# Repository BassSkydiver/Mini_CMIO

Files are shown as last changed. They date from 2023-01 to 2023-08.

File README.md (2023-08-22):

# CMIOBoard
A tiny, compact IO board for the raspberry compute modules 1/3/3+

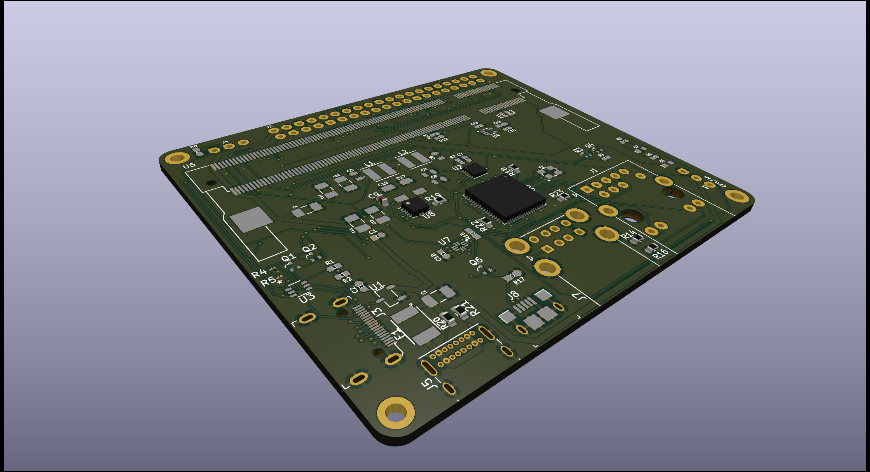
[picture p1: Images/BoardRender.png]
Top View


## Features:
IO Ports:  
* USB-C (Power/USB 2.0)
* HDMI
* USB-Micro B (Slave port)
* Dual-USB-A 2.0
* Ethernet

## Other:
* Three pin 5V fan header
* Three pin boot selector
* 40 pin standard Raspberry Pi GPIO
* 4x2.2mm mounting holes
* Power LED (Red)
* Boot LED (Green)

## Dimensions:
75.66mm x 65.63mm  
2.844mm radius rounded corners
2.2mm diameter mounting holes (M2 or US #1/2 screws)  
69.97mm center distance between horizontally aligned mounting holes.  
59.94mm center distance between vertically aligned mounting holes.  
## Important!
The Raspberry Pi Compute Module requires a 5v, 2+ Amp power supply. (5.1V Recommended)
This board was made by a complete amatuer and should be avoided or subject to harsh scrutiny before used in a real application.

## Directions to Install:
1. Make sure your KiCAD verison is 7.0.6 or higher
2. Rename the "Footprints" folder to "Footprints.pretty"
3. Open the "RPCM1 IO Board.kicad_pro" file
4. Add symbols and footprints from this directory into the "Project Specific Libraries" section of the Symbol Library Manager and the Footprint Library Manager
5. Do whatever you want I guess :)

*License: GNU General Public License v3.0*  
*[gnu.org/licenses/gpl-3.0](https://www.gnu.org/licenses/gpl-3.0.en.html)*

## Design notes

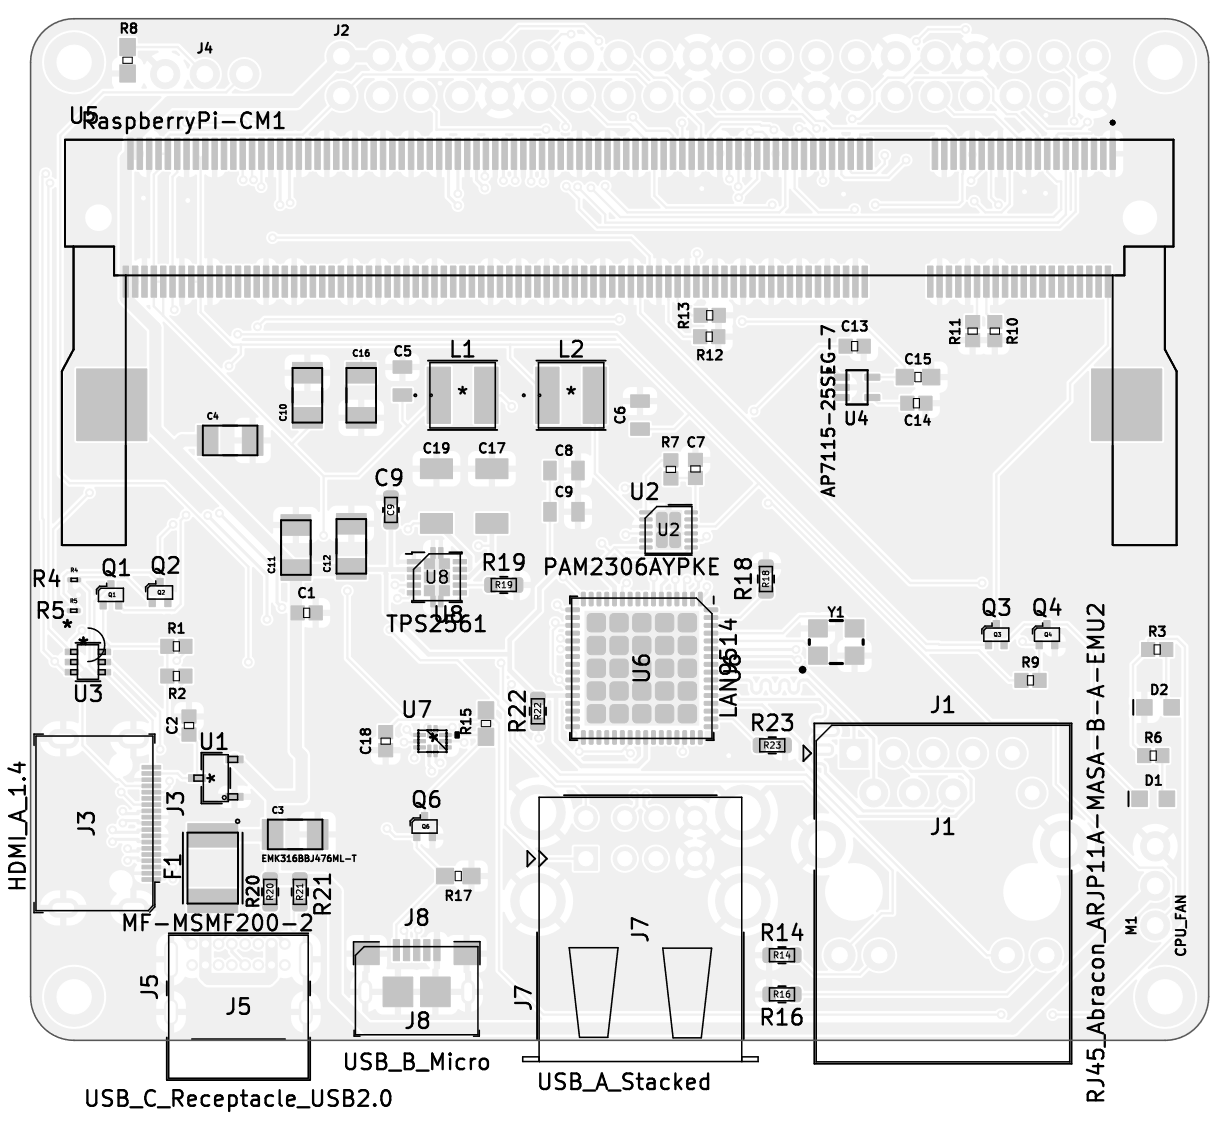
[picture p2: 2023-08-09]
Images/BoardTop.png

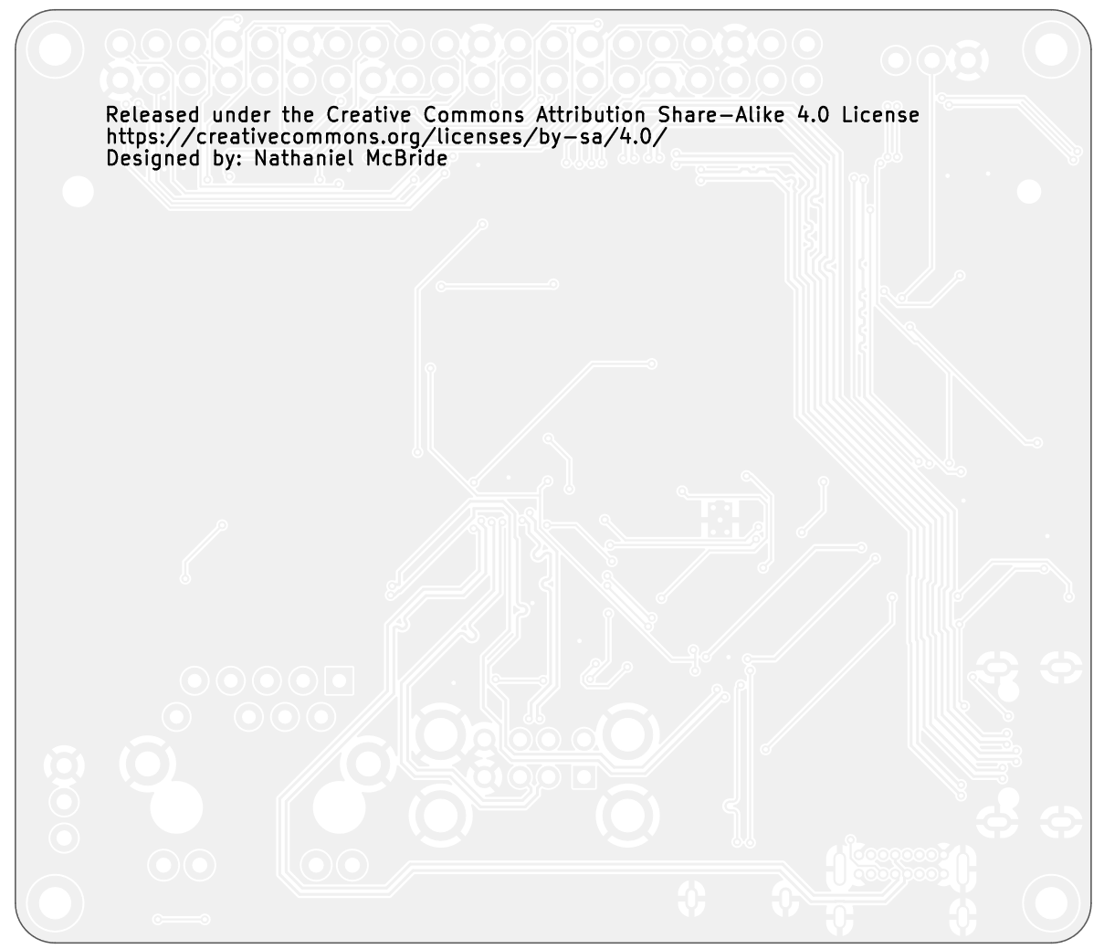
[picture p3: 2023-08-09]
Images/BoardBot.png

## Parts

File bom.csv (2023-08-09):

Reference | Value | Footprint | Datasheet | ARROW_ELECTRONICS-PURCHASE-URL | AVAILABILITY | Category | DESCRIPTION | DIGIKEY-PURCHASE-URL | DK_Datasheet_Link | DK_Detail_Page | Description | Digi-Key_PN | Family | Field4 | Height | MANUFACTURER | MF | MOUSER-PURCHASE-URL | MP | MPN | Manufacturer | Manufacturer_Name | Manufacturer_Part_Number | Mouser Part Number | Mouser Price/Stock | PACKAGE | PARTREV | PRICE | STANDARD | Status | Qty
C1, C2, C7, C14 | 0.1UF-0402 | Capacitors:0402 |  |  |  |  |  |  |  |  |  |  |  | CAP-12416 |  |  |  |  |  |  |  |  |  |  |  |  |  |  |  |  | 4
C3, C4, C10-C12, C16 | EMK316BBJ476ML-T | custom:CAPC3216X190N |  |  |  |  |  |  |  |  |  |  |  |  |  |  |  |  |  |  |  |  |  |  |  |  |  |  |  |  | 6
C5, C6 | 10UF-0805 | Capacitors:0805 |  |  |  |  |  |  |  |  |  |  |  | CAP-11330 |  |  |  |  |  |  |  |  |  |  |  |  |  |  |  |  | 2
C8 | 10UF-0805-10V-10% | Capacitors:0805 |  |  |  |  |  |  |  |  |  |  |  | CAP-11330 |  |  |  |  |  |  |  |  |  |  |  |  |  |  |  |  | 1
C8/9 | 10UF-0805 | Capacitors:0805 |  |  |  |  |  |  |  |  |  |  |  | CAP-11330 |  |  |  |  |  |  |  |  |  |  |  |  |  |  |  |  | 1
C9 | 0.1UF-0603-25V-5% | Capacitor_SMD:C_0603_1608Metric |  |  |  |  |  |  |  |  |  |  |  | CAP-08604 |  |  |  |  |  |  |  |  |  |  |  |  |  |  |  |  | 1
C13 | 1.0UF-0402 | Capacitors:0402 |  |  |  |  |  |  |  |  |  |  |  | CAP-12417 |  |  |  |  |  |  |  |  |  |  |  |  |  |  |  |  | 1
C15 | 4.7UF-1206 | Capacitors:0603 |  |  |  |  |  |  |  |  |  |  |  |  |  |  |  |  |  |  |  |  |  |  |  |  |  |  |  |  | 1
C17, C19 | AMK325ABJ157MM-P | Capacitors:1210 | https://media.digikey.com/pdf/Data%20Sheets/Taiyo%20Yuden%20PDFs%20URL%20links/AMK325ABJ157MM-P_SS.pdf |  |  |  |  |  |  |  |  |  |  |  | 2.8 |  |  |  |  |  |  | TAIYO YUDEN | AMK325ABJ157MM-P | 963-AMK325ABJ157MM-P | https://www.mouser.co.uk/ProductDetail/Taiyo-Yuden/AMK325ABJ157MM-P?qs=GTwwGWkfii23ISUqIFLJMQ%3D%3D |  |  |  |  |  | 2
C18 | 0.1UF-0402-16V-10% | Capacitors:0402 |  |  |  |  |  |  |  |  |  |  |  | CAP-12416 |  |  |  |  |  |  |  |  |  |  |  |  |  |  |  |  | 1
D1 | LED-GREEN0603 | LED:LED-0603 |  |  |  |  |  |  |  |  |  |  |  | DIO-00821 |  |  |  |  |  |  |  |  |  |  |  |  |  |  |  |  | 1
D2 | LED-RED0603 | LED:LED-0603 |  |  |  |  |  |  |  |  |  |  |  | DIO-00819 |  |  |  |  |  |  |  |  |  |  |  |  |  |  |  |  | 1
F1 | MF-MSMF200-2 | custom:MF-MSMF200-2 |  | https://snapeda.com/shop?store=Arrow+Electronics&id=143366 | Good |  | Polymeric PTC Resettable Fuse 8V 2A Ih Surface Mount 1812 (4532 Metric), Concave | https://snapeda.com/shop?store=DigiKey&id=143366 |  |  |  |  |  |  |  |  | Bourns | https://snapeda.com/shop?store=Mouser&id=143366 | MF-MSMF200-2 |  |  |  |  |  |  | 1812 Bourns |  | None |  |  | 1
H1-H4 | MountingHole | MountingHole:MountingHole_2.2mm_M2_DIN965_Pad_TopBottom | ~ |  |  |  |  |  |  |  |  |  |  |  |  |  |  |  |  |  |  |  |  |  |  |  |  |  |  |  | 4
J1 | RJ45_Abracon_ARJP11A-MASA-B-A-EMU2 | Connector_RJ:RJ45_Abracon_ARJP11A-MA_Horizontal | https://abracon.com/Magnetics/lan/ARJP11A.PDF |  |  |  |  |  |  |  |  |  |  |  |  |  |  |  |  |  |  |  |  |  |  |  |  |  |  |  | 1
J2 | RASPBERRYPI-40-PIN-GPIO_PTH | Connectors:2X20_NOSILK |  |  |  |  |  |  |  |  |  |  |  | CONN-12263 |  |  |  |  |  |  |  |  |  |  |  |  |  |  |  |  | 1
J3 | HDMI_A_1.4 | digikey-footprints:HDMI_Mini_Female_2001-1-2-21-00-BK | https://en.wikipedia.org/wiki/HDMI |  |  |  |  |  |  |  |  |  |  |  |  |  |  |  |  |  |  |  |  |  |  |  |  |  |  |  | 1
J4 | CONN_03 | Connectors:1X03_NO_SILK |  |  |  |  |  |  |  |  |  |  |  | XXX-00000 |  |  |  |  |  |  |  |  |  |  |  |  |  |  |  |  | 1
J5 | USB_C_Receptacle_USB2.0 | Connector_USB:USB_C_Receptacle_GCT_USB4085 | https://www.usb.org/sites/default/files/documents/usb_type-c.zip |  |  |  |  |  |  |  |  |  |  |  |  |  |  |  |  |  |  |  |  |  |  |  |  |  |  |  | 1
J7 | USB_A_Stacked | Connector_USB:USB_A_CUI_UJ2-ADH-TH_Horizontal_Stacked | ~ |  |  |  |  |  |  |  |  |  |  |  |  |  |  |  |  |  |  |  |  |  |  |  |  |  |  |  | 1
J8 | USB_B_Micro | digikey-footprints:USB_Micro_B_Female_10118193-0001LF | ~ |  |  |  |  |  |  |  |  |  |  |  |  |  |  |  |  |  |  |  |  |  |  |  |  |  |  |  | 1
L1, L2 | SRN4018-4R7M | custom:SRN4018-4R7M |  |  |  |  |  |  |  |  |  |  |  |  |  |  |  |  |  |  |  |  |  |  |  |  |  |  |  |  | 2
M1 | Fan_3pin | Connectors:1X03_NO_SILK | http://www.hardwarecanucks.com/forum/attachments/new-builds/16287d1330775095-help-chassis-power-fan-connectors-motherboard-asus_p8z68.jpg |  |  |  |  |  |  |  |  |  |  |  |  |  |  |  |  |  |  |  |  |  |  |  |  |  |  |  | 1
Q1-Q4, Q6 | DMG1012T-7 | digikey-footprints:SOT-523 | https://www.diodes.com/assets/Datasheets/ds31783.pdf |  |  | Discrete Semiconductor Products |  |  | https://www.diodes.com/assets/Datasheets/ds31783.pdf | /product-detail/en/diodes-incorporated/DMG1012T-7/DMG1012T-7DICT-ND/2181232 | MOSFET N-CH 20V 630MA SOT-523 | DMG1012T-7DICT-ND | Transistors - FETs, MOSFETs - Single |  |  |  |  |  |  | DMG1012T-7 | Diodes Incorporated |  |  |  |  |  |  |  |  | Active | 5
R1, R2 | RESISTOR0402 | Resistors:0402 |  |  |  |  |  |  |  |  |  |  |  |  |  |  |  |  |  |  |  |  |  |  |  |  |  |  |  |  | 2
R3 | 470OHM | Resistors:0402 |  |  |  |  |  |  |  |  |  |  |  | RES-07869 |  |  |  |  |  |  |  |  |  |  |  |  |  |  |  |  | 1
R4, R5 | 100K-0402 | Resistor_SMD:R_01005_0402Metric |  |  |  |  |  |  |  |  |  |  |  | RES-13495 |  |  |  |  |  |  |  |  |  |  |  |  |  |  |  |  | 2
R6 | 470-0402 | Resistors:0402 |  |  |  |  |  |  |  |  |  |  |  | RES-07869 |  |  |  |  |  |  |  |  |  |  |  |  |  |  |  |  | 1
R7 | 100k-0402 | Resistors:0402 |  |  |  |  |  |  |  |  |  |  |  | RES-13495 |  |  |  |  |  |  |  |  |  |  |  |  |  |  |  |  | 1
R8 | 47K-0603 | Resistors:0603 |  |  |  |  |  |  |  |  |  |  |  | RES-07871 |  |  |  |  |  |  |  |  |  |  |  |  |  |  |  |  | 1
R9 | 100K-0402 | Resistors:0402 |  |  |  |  |  |  |  |  |  |  |  | RES-13495 |  |  |  |  |  |  |  |  |  |  |  |  |  |  |  |  | 1
R10-R13 | 100KOHM-0402-1_16W-1% | Resistors:0402 |  |  |  |  |  |  |  |  |  |  |  | RES-13495 |  |  |  |  |  |  |  |  |  |  |  |  |  |  |  |  | 4
R14, R16 | 100OHM-0603 | Resistor_SMD:R_0603_1608Metric |  |  |  |  |  |  |  |  |  |  |  | RES-12438 |  |  |  |  |  |  |  |  |  |  |  |  |  |  |  |  | 2
R15 | 47KOHM-0603-1_10W | Resistors:0603 |  |  |  |  |  |  |  |  |  |  |  | RES-07871 |  |  |  |  |  |  |  |  |  |  |  |  |  |  |  |  | 1
R17 | 47KOHM-0603-1_10W-1% | Resistors:0603 |  |  |  |  |  |  |  |  |  |  |  | RES-07871 |  |  |  |  |  |  |  |  |  |  |  |  |  |  |  |  | 1
R18 | 12KOHM-0603-1% | Resistor_SMD:R_0603_1608Metric |  |  |  |  |  |  |  |  |  |  |  | RES-10327 |  |  |  |  |  |  |  |  |  |  |  |  |  |  |  |  | 1
R19 | 100KOHM-0603-1_10W-1% | Resistor_SMD:R_0603_1608Metric |  |  |  |  |  |  |  |  |  |  |  | RES-07828 |  |  |  |  |  |  |  |  |  |  |  |  |  |  |  |  | 1
R20, R21 | 47KOHM-0603-1_10W-1% | Resistor_SMD:R_0603_1608Metric |  |  |  |  |  |  |  |  |  |  |  | RES-07871 |  |  |  |  |  |  |  |  |  |  |  |  |  |  |  |  | 2
R22 | 10KOHM-0603-1_10W-1% | Resistor_SMD:R_0603_1608Metric |  |  |  |  |  |  |  |  |  |  |  | RES-00824 |  |  |  |  |  |  |  |  |  |  |  |  |  |  |  |  | 1
R23 | 12KOHM-0603 | Resistor_SMD:R_0603_1608Metric |  |  |  |  |  |  |  |  |  |  |  | RES-10327 |  |  |  |  |  |  |  |  |  |  |  |  |  |  |  |  | 1
U1 | AP2331W-7 | custom:AP2331W-7 |  |  |  |  |  |  |  |  |  |  |  |  |  |  |  |  |  |  |  |  |  |  |  |  |  |  |  |  | 1
U2 | PAM2306AYPKE | Package_DFN_QFN:WDFN-12-1EP_3x3mm_P0.45mm_EP1.7x2.5mm | https://www.diodes.com/assets/Datasheets/PAM2306.pdf |  |  |  |  |  |  |  |  |  |  |  |  |  |  |  |  |  |  |  |  |  |  |  |  |  |  |  | 1
U3 | PESD3V3L5UY | custom:PESD3V3L5UY |  |  |  |  |  |  |  |  |  |  |  |  |  |  |  |  |  |  |  |  |  |  |  |  |  |  |  |  | 1
U4 | AP7115-25SEG-7 | custom:AP7115-25SEG |  |  |  |  |  |  |  |  |  |  |  |  |  | Diodes Inc. |  |  |  |  |  |  |  |  |  |  | 12 | None | IPC7351B |  | 1
U5 | RaspberryPi-CM1 | custom:TE_1717254-4 | https://www.raspberrypi.org/documentation/hardware/computemodule/datasheets/rpi_DATA_CM_1p0.pdf |  |  |  |  |  |  |  |  |  |  |  |  |  |  |  |  |  |  |  |  |  |  |  |  |  |  |  | 1
U6 | LAN9514 | Package_DFN_QFN:QFN-64-1EP_9x9mm_P0.5mm_EP7.3x7.3mm | http://ww1.microchip.com/downloads/en/DeviceDoc/00002306A.pdf |  |  |  |  |  |  |  |  |  |  |  |  |  |  |  |  |  |  |  |  |  |  |  |  |  |  |  | 1
U7 | FSUSB42UMX | custom:FSUSB42UMX |  |  |  |  |  |  |  |  |  |  |  |  |  |  |  |  |  |  |  |  |  |  |  |  |  |  |  |  | 1
U8 | TPS2561 | Package_SON:VSON-10-1EP_3x3mm_P0.5mm_EP1.65x2.4mm_ThermalVias | http://www.ti.com/lit/ds/symlink/tps2561.pdf |  |  |  |  |  |  |  |  |  |  |  |  |  |  |  |  |  |  |  |  |  |  |  |  |  |  |  | 1
Y1 | ECS-250-10-37B-CTN-TR | Clocks:CRYSTAL-SMD-3.2X2.5MM |  |  |  |  |  |  |  |  |  |  |  |  |  | ECS INC |  |  |  |  |  |  |  |  |  | SMD-4 ECX | 2017 |  | Manufacturer Recommendation |  | 1

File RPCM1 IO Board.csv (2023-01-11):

Source: | C:\Users\natha\OneDrive\Documents\PCB Designs\RPCM1 IO Board\RPCM1 IO Board.kicad_sch
Date: | 1/9/2023 3:18:24 PM
Tool: | Eeschema (6.0.9)
Generator: | C:\Program Files\KiCad\6.0\bin\scripting\plugins/bom_csv_grouped_by_value_with_fp.py
Component Count: | 60
Ref | Qnty | Cmp name | DK Name | Description | Datasheet | Manufacturer | DK Link | Price (Single) | Price (Total)
C1, C2, C6, C12, C14, | 5 | 0.1UF-0402-16V-10% | 04026D104KAT2A | 0.1 µF ±10% 6.3V Ceramic Capacitor X5R 0402 (1005 Metric) | https://datasheets.kyocera-avx.com/cx5r.pdf | KYOCERA AVX | https://www.digikey.com/en/products/detail/kyocera-avx/04026D104KAT2A/1597649 | $0.10 | $0.50
C3, C9, C10, C15, C16, C17, | 6 | EMK316BBJ476ML-T | CL31A476MQHNNWE | CAP CER 0.1UF 6.3V X5R 0402 | https://www.samsungsem.com/kr/support/product-search/mlcc/CL31A476MQHNNWE.jsp | Samsung Electro-Mechanics | https://www.digikey.com/en/products/detail/samsung-electro-mechanics/CL31A476MQHNNWE/3888722 | $0.41 | $2.46
C4, C5, C7, C8, | 4 | 10UF-0805-10V-10% | CL21A106KOQNNNE | CAP CER 10UF 16V X5R 0805 | https://media.digikey.com/pdf/Data%20Sheets/Samsung%20PDFs/CL21A106KOQNNNE_Spec.pdf | Samsung Electro-Mechanics | https://www.digikey.com/en/products/detail/samsung-electro-mechanics/CL21A106KOQNNNE/3886754 | $0.10 | $0.40
C11, | 1 | 1.0UF-0402-16V-10% | CC0402KRX5R5BB105 | CAP CER 1UF 6.3V X5R 0402 | https://www.yageo.com/upload/media/product/productsearch/datasheet/mlcc/UPY-GPHC_X5R_4V-to-50V_26.pdf | YAGEO | https://www.digikey.com/en/products/detail/yageo/CC0402KRX5R5BB105/2833603 | $0.11 | $0.11
C13, | 1 | 4.7UF-1206-16V-_+80_-20%_ | CL10A475KP8NNNC | CAP CER 4.7UF 10V X5R 0603 | https://media.digikey.com/pdf/Data%20Sheets/Samsung%20PDFs/CL10A475KP8NNNC_Spec.pdf | Samsung Electro-Mechanics | https://www.digikey.com/en/products/detail/samsung-electro-mechanics/CL10A475KP8NNNC/3886702 | $0.10 | $0.10
D1, | 1 | LED-GREEN0603 | LTST-C191KGKT | LED GREEN CLEAR SMD | https://optoelectronics.liteon.com/upload/download/DS22-2000-228/LTST-C191KGKT.PDF | Lite-On Inc. | https://www.digikey.com/en/products/detail/liteon/LTST-C191KGKT/386835 | $0.26 | $0.26
D2, | 1 | LED-RED0603 | SML-D12U8WT86 | Red 620nm LED Indication - Discrete 2.2V 0603 (1608 Metric) | https://fscdn.rohm.com/en/products/databook/datasheet/opto/led/chip_mono/sml-d12x8_d13x8-e.pdf | Rohm Semiconductor | https://www.digikey.com/en/products/detail/rohm-semiconductor/SML-D12U8WT86/1641799 | $0.37 | $0.37
F1, | 1 | MF-MSMF200-2 | MF-MSMF200-2 | Polymeric PTC Resettable Fuse 8V 2 A Ih Surface Mount 1812 (4532 Metric), Concave | https://www.bourns.com/docs/product-datasheets/mf-msmf.pdf | Bourns Inc. | https://www.digikey.com/en/products/detail/bourns-inc/MF-MSMF200-2/662824 | $0.61 | $0.61
H1, H2, H3, H4, | 4 | MountingHole | x | Grounded Mounting Hole | x | x | x | x | x
J1, | 1 | USB4085-GF-A | USB4085-GF-A | USB-C (USB TYPE-C) USB 2.0 Receptacle Connector 24 (16+8 Dummy) Position Through Hole, Right Angle | https://gct.co/files/drawings/usb4085.pdf | GCT | https://www.digikey.com/en/products/detail/gct/USB4085-GF-A/9859662 | $0.94 | $0.94
J2, | 1 | HDMI_A_1.4 | 10029449-111RLF | HDMI HDMI 1.4 Receptacle Connector 19 Position Surface Mount, Right Angle; Through Hole | https://www.amphenol-cs.com/media/wysiwyg/files/drawing/10029449.pdf | Amphenol ICC (FCI) | https://www.digikey.com/en/products/detail/amphenol-cs-fci/10029449-111RLF/2785386 | $1.26 | $1.26
J3, | 1 | CONN_02POGO_PIN_HOLES_ONLY | 61300211121 | CONN HEADER VERT 2POS 2.54MM | https://www.we-online.com/katalog/datasheet/6130xx11121.pdf | Würth Elektronik | https://www.digikey.com/en/products/detail/w%C3%BCrth-elektronik/61300211121/4846823 | $0.13 | $0.13
J4, | 1 | CONN_03 | M20-9990345 | Connector Header Through Hole 3 position 0.100" (2.54mm) | https://cdn.harwin.com/pdfs/C001XX_M20_Series_Connectors.pdf | Harwin Inc. | https://www.digikey.com/en/products/detail/harwin-inc/M20-9990345/3728227 | $0.19 | $0.19
J5, | 1 | USB_A | 1002-021-01000 | USB-A (USB TYPE-A) USB 2.0 Receptacle Connector 4 Position Through Hole | http://www.cnctech.us/pdfs/1002-021-01000.pdf | CNC Tech | https://www.digikey.com/en/products/detail/cnc-tech/1002-021-01000/3466946 | $1.11 | $1.11
J6, | 1 | USB_A | 87520-0010BLF | USB-A (USB TYPE-A) USB 2.0 Receptacle Connector 4 Position Through Hole, Right Angle | https://www.amphenol-cs.com/media/wysiwyg/files/drawing/87520.pdf | Amphenol ICC (FCI) | https://www.digikey.com/en/products/detail/amphenol-cs-fci/87520-0010BLF/1001359 | $0.95 | $0.95
J7, | 1 | USB_B_Micro | 10118193-0001LF | USB - micro B USB 2.0 Receptacle Connector 5 Position Surface Mount, Right Angle; Through Hole | https://cdn.amphenol-cs.com/media/wysiwyg/files/documentation/datasheet/inputoutput/io_usb_micro.pdf | Amphenol ICC (FCI) | https://www.digikey.com/en/products/detail/amphenol-cs-fci/10118193-0001LF/2785388 | $0.46 | $0.46
L1, L2, | 2 | SRN4018-4R7M | SRN4018-4R7M | 4.7 µH Semi-Shielded Drum Core, Wirewound Inductor 1.9 A 84mOhm Max Nonstandard | https://www.bourns.com/docs/Product-Datasheets/SRN4018.pdf | Bourns Inc. | https://www.digikey.com/en/products/detail/bourns-inc/SRN4018-4R7M/3821622 | $0.50 | $1.00
M1, | 1 | Fan_CPU_4pin | 640452-4 | Connector Header Through Hole 4 position 0.100" (2.54mm) | https://www.te.com/commerce/DocumentDelivery/DDEController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 | TE Connectivity AMP Connectors | https://www.digikey.com/en/products/detail/te-connectivity-amp-connectors/640452-4/108976 | $0.66 | $0.66
Q1, Q2, Q3, Q4, Q5, | 5 | DMG1012T-7 | DMG1012T-7 | N-Channel 20 V 630mA (Ta) 280mW (Ta) Surface Mount SOT-523 | https://www.diodes.com/assets/Datasheets/DMG1012T.pdf | Diodes Incorporated | https://www.digikey.com/en/products/detail/diodes-incorporated/DMG1012T-7/2174582 | $0.33 | $1.65
R1, R2, | 2 | RESISTOR0402 | RC0402FR-071K74L | 1.74 kOhms ±1% 0.063W, 1/16W Chip Resistor 0402 (1005 Metric) Moisture Resistant Thick Film | https://www.yageo.com/upload/media/product/productsearch/datasheet/rchip/PYu-RC_Group_51_RoHS_L_12.pdf | YAGEO | https://www.digikey.com/en/products/detail/yageo/RC0402FR-071K74L/5280906 | $0.10 | $0.20
R3, R5, R4, R8, R9, R10, R12, R13, | 8 | 100KOHM-0402-1_16W-1% | RC0402FR-07100KL | 100 kOhms ±1% 0.063W, 1/16W Chip Resistor 0402 (1005 Metric) Moisture Resistant Thick Film | https://www.yageo.com/upload/media/product/productsearch/datasheet/rchip/PYu-RC_Group_51_RoHS_L_12.pdf | YAGEO | https://www.digikey.com/en/products/detail/yageo/RC0402FR-07100KL/726526 | $0.10 | $0.80
R6, R15, | 2 | 470OHM | RC0402FR-07470RL | 470 Ohms ±1% 0.063W, 1/16W Chip Resistor 0402 (1005 Metric) Moisture Resistant Thick Film | https://www.yageo.com/upload/media/product/productsearch/datasheet/rchip/PYu-RC_Group_51_RoHS_L_12.pdf | YAGEO | https://www.digikey.com/en/products/detail/yageo/RC0402FR-07470RL/726619 | $0.10 | $0.20
R7, R11, R14, | 3 | 47KOHM-0603-1_10W-1% | RC0603FR-0747KL | 47 kOhms ±1% 0.1W, 1/10W Chip Resistor 0603 (1608 Metric) Moisture Resistant Thick Film | https://www.yageo.com/upload/media/product/productsearch/datasheet/rchip/PYu-RC_Group_51_RoHS_L_12.pdf | YAGEO | https://www.digikey.com/en/products/detail/yageo/RC0603FR-0747KL/727253 | $0.10 | $0.30
U1, | 1 | AP2331W-7 | AP2331W-7 | Current Switch Regulator High-Side 200mA SC-59-3 | https://www.diodes.com/assets/Datasheets/AP2331.pdf | Diodes Incorporated | https://www.digikey.com/en/products/detail/diodes-incorporated/AP2331W-7/4251553 | $0.43 | $0.43
U2, | 1 | PESD3V3L5UY | PESD3V3L5UY,115 | 12V Clamp 2.5A (8/20µs) Ipp Tvs Diode Surface Mount 6-TSSOP | https://assets.nexperia.com/documents/data-sheet/PESDXL5UF_V_Y.pdf | Nexperia USA Inc. | https://www.digikey.com/en/products/detail/nexperia-usa-inc/PESD3V3L5UY-115/1157444 | $0.43 | $0.43
U3, | 1 | PAM2306AYPKE | PAM2306AYPKE | Buck Switching Regulator IC Positive Fixed 1.8V, 3.3V 2 Output 1A 12-WFDFN Exposed Pad | https://www.diodes.com/assets/Datasheets/PAM2306.pdf | Diodes Incorporated | https://www.digikey.com/en/products/detail/diodes-incorporated/PAM2306AYPKE/5306176 | $0.76 | $0.76
U4, | 1 | AP7115-25SEG-7 | AP7115-25SEG-7 | Linear Voltage Regulator IC Positive Fixed 1 Output 150mA SOT-353 | https://media.digikey.com/pdf/Data%20Sheets/Diodes%20PDFs/AP7115_Sept2017_DS.pdf | Diodes Incorporated | https://www.digikey.com/en/products/detail/diodes-incorporated/AP7115-25SEG-7/2044527 | $0.42 | $0.42
U5, | 1 | RaspberryPi-CM1 | 1717254-4 | 200 Position SODIMM DDR2 SDRAM Socket Surface Mount, Right Angle | https://www.te.com/commerce/DocumentDelivery/DDEController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 | TE Connectivity AMP Connectors | https://www.digikey.com/en/products/detail/te-connectivity-amp-connectors/1717254-4/9346779 | $7.91 | $7.91
U6, | 1 | FSUSB42UMX | FSUSB42UMX | USB Switch IC 1 Channel 10-UMLP (1.8x1.4) | https://rocelec.widen.net/view/pdf/a7amyaouts/FAIR-S-A0001171768-1.pdf?t.download=true&u=5oefqw | onsemi | https://www.digikey.com/en/products/detail/onsemi/FSUSB42UMX/1642609 | $0.75 | $0.75
 |  |  |  |  |  |  |  |  | $25.36
External Parts: | 11
Type | Qnty | Cmp name | DK Name | Description | Datasheet | Manufacturer | DK Link | Price (Single) | Price (Total)
Cable | 1 | USB A to C Cable | DH-20M50052 | USB 2.0 Cable A Male to C Male 3.28' (1.00m) Shielded | https://media.digikey.com/pdf/Data%20Sheets/Cvilux%20USA%20PDFs/DH-20M50052_Dwg.pdf | Cvilux USA | https://www.digikey.com/en/products/detail/cvilux-usa/DH-20M50052/13177409 | $1.68 | $1.68
Cable | 1 | USB A to C Cable | 4053 | USB 2.0, USB 3.2 Gen 2 (USB 3.1 Gen 2, Superspeed+ (USB 3.1)) Cable C Female to A Male 0.98' (300.0mm) Unshielded | https://cdn-shop.adafruit.com/product-files/4053/4053_PCM-A-002_TYPE_C_F-USB_A_M_30cm_SCREW.pdf | Adafruit Industries LLC | https://www.digikey.com/en/products/detail/adafruit-industries-llc/4053/9997695 | $4.95 | $4.95
Mounting | 4 | 10-32 Threaded Inserts | 1032X375H | Insert Yellow 0.30" Dia x 0.38" H (7.5mm x 9.5mm) | https://media.digikey.com/pdf/Data%20Sheets/RAF%20Elect%20PDFs/product_Cat.pdf | Tri-Star Industries, Inc. | https://www.digikey.com/en/products/detail/tri-star-industries-inc/1032X375H/13535332 | $0.33 | $1.32
Mounting | 4 | 10-32 Screw | 9909 | #10-32 Pan Head Machine Screw Phillips Drive Stainless Steel | https://www.keyelco.com/userAssets/file/M65p135.pdf | Keystone Electronics | https://www.digikey.com/en/products/detail/keystone-electronics/9909/317329 | $0.28 | $1.12
Cooling | 1 | 40mm 5v Fan | CFM-4010B-065-251-22 | Fan Tubeaxial 5VDC Square - 40mm L x 40mm H Ball 5.5 CFM (0.154m³/min) 4 Wire Leads | https://www.cuidevices.com/product/resource/cfm-40b.pdf | CUI Devices | https://www.digikey.com/en/products/detail/cui-devices/CFM-4010B-065-251-22/16582006 | $8.81 | $8.81
Cooling | 1 | 14mm x 14mm heatsink | HSB03-141406 | Heat Sink BGA Aluminum Alloy 2.1W @ 75°C Top Mount | https://www.cuidevices.com/product/resource/hsb03-141406.pdf | CUI Devices | https://www.digikey.com/en/products/detail/cui-devices/HSB03-141406/14567064 | $0.74 | $0.74
 |  |  |  |  |  |  |  |  | $18.62
 |  |  |  |  |  |  |  |  | $43.98

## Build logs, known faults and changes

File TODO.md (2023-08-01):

## Todo:
1. Redo the entire project with good schematic and PCB design practices!
2. Design case with support for a 40mm fan, 10-32 mounting screws, and a power switch.
3. Add dedicated Ethernet.
4. Expand USB selection to Dual USB-A, and USB-C with data.
5. Add small, dedicated GPIO pins with 5V, 3V3, 1V8, and GND pins.
6. Power over Ethernet
7. Probe Points for debugging
8. 3.5 mm audio jack via GPIO pins 40/45 (as seen [here](https://www.hasseb.fi/pi/schematics.pdf))
9. Re-add 0 ohm resistors from Raspberry Pi Foundantion schematics

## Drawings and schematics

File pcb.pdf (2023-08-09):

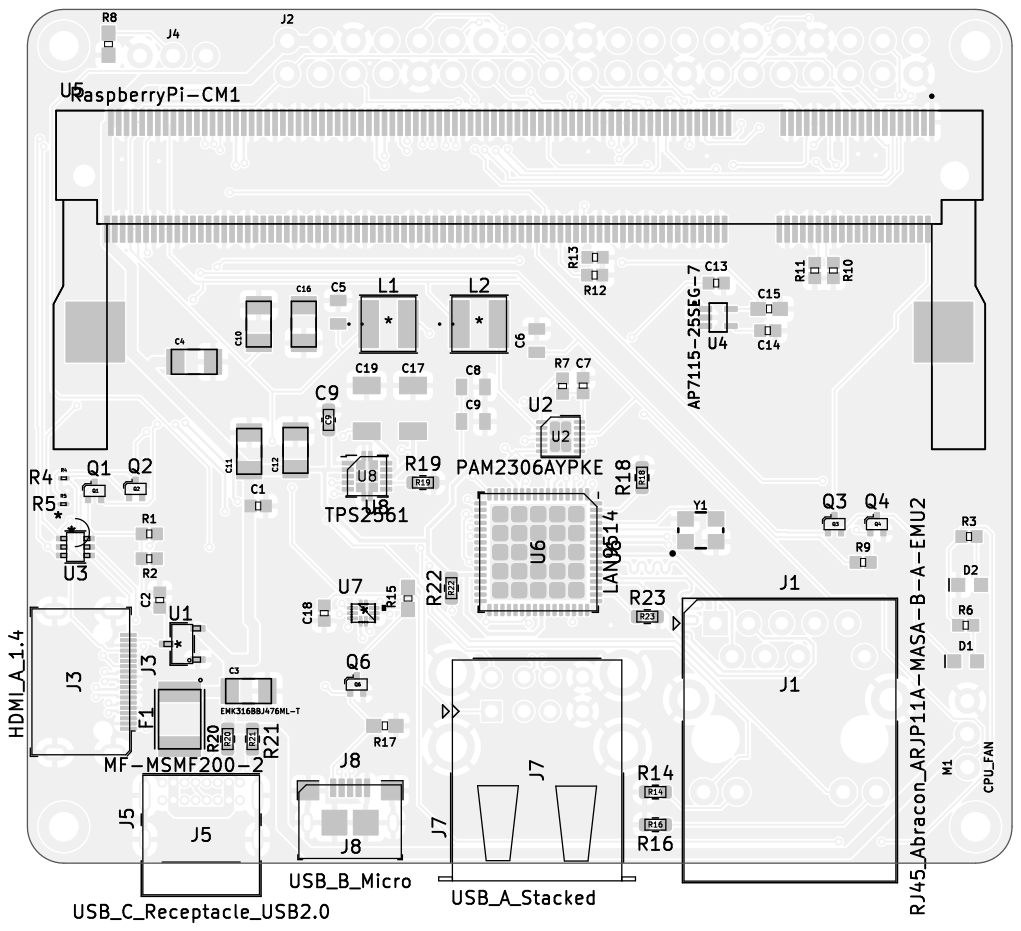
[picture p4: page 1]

Id: 1/1 Title: Compute Module IO Board

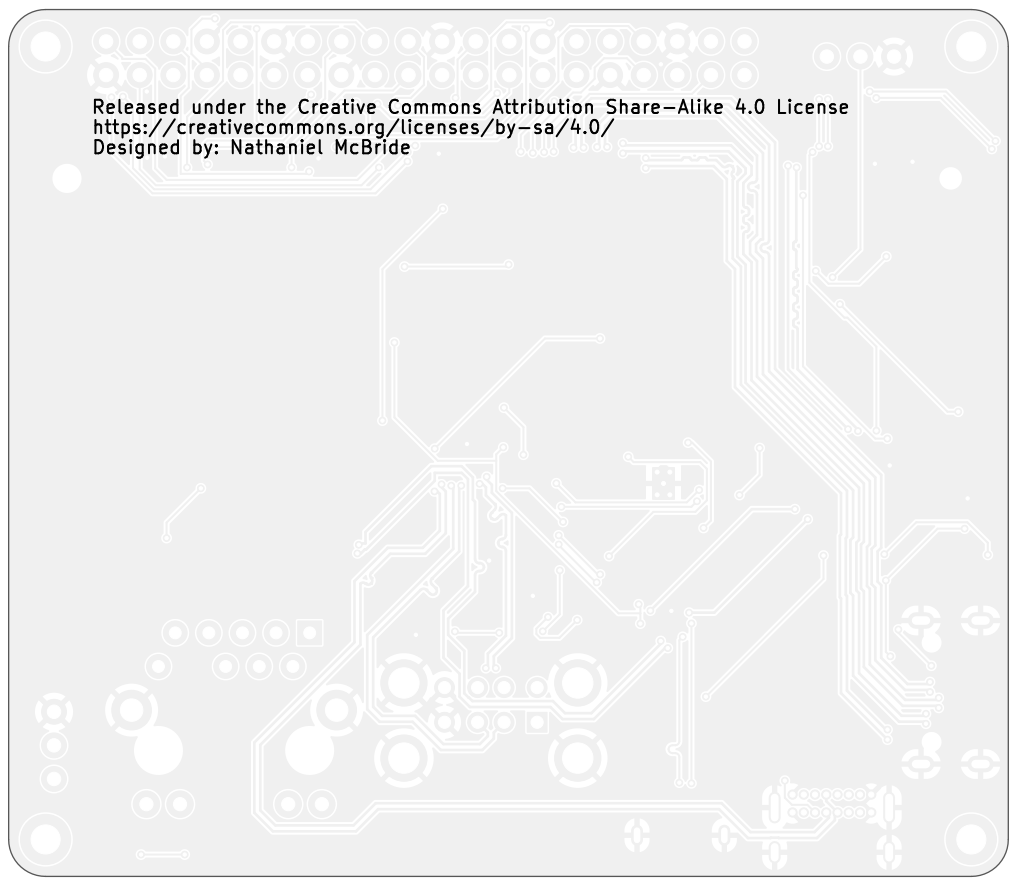
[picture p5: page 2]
D Date: 2023-08-08 KiCad; kicad; 7.0.6 Size: A4; Rev: 2.1; File: RPCM1; Board.kicad_pcb Sheet: creativecommons.org/licenses/by/4.0/ License: CC; BY 4.0 Author:; Nathaniel; McBride

Id: 1/1 Title: Compute Module IO Board

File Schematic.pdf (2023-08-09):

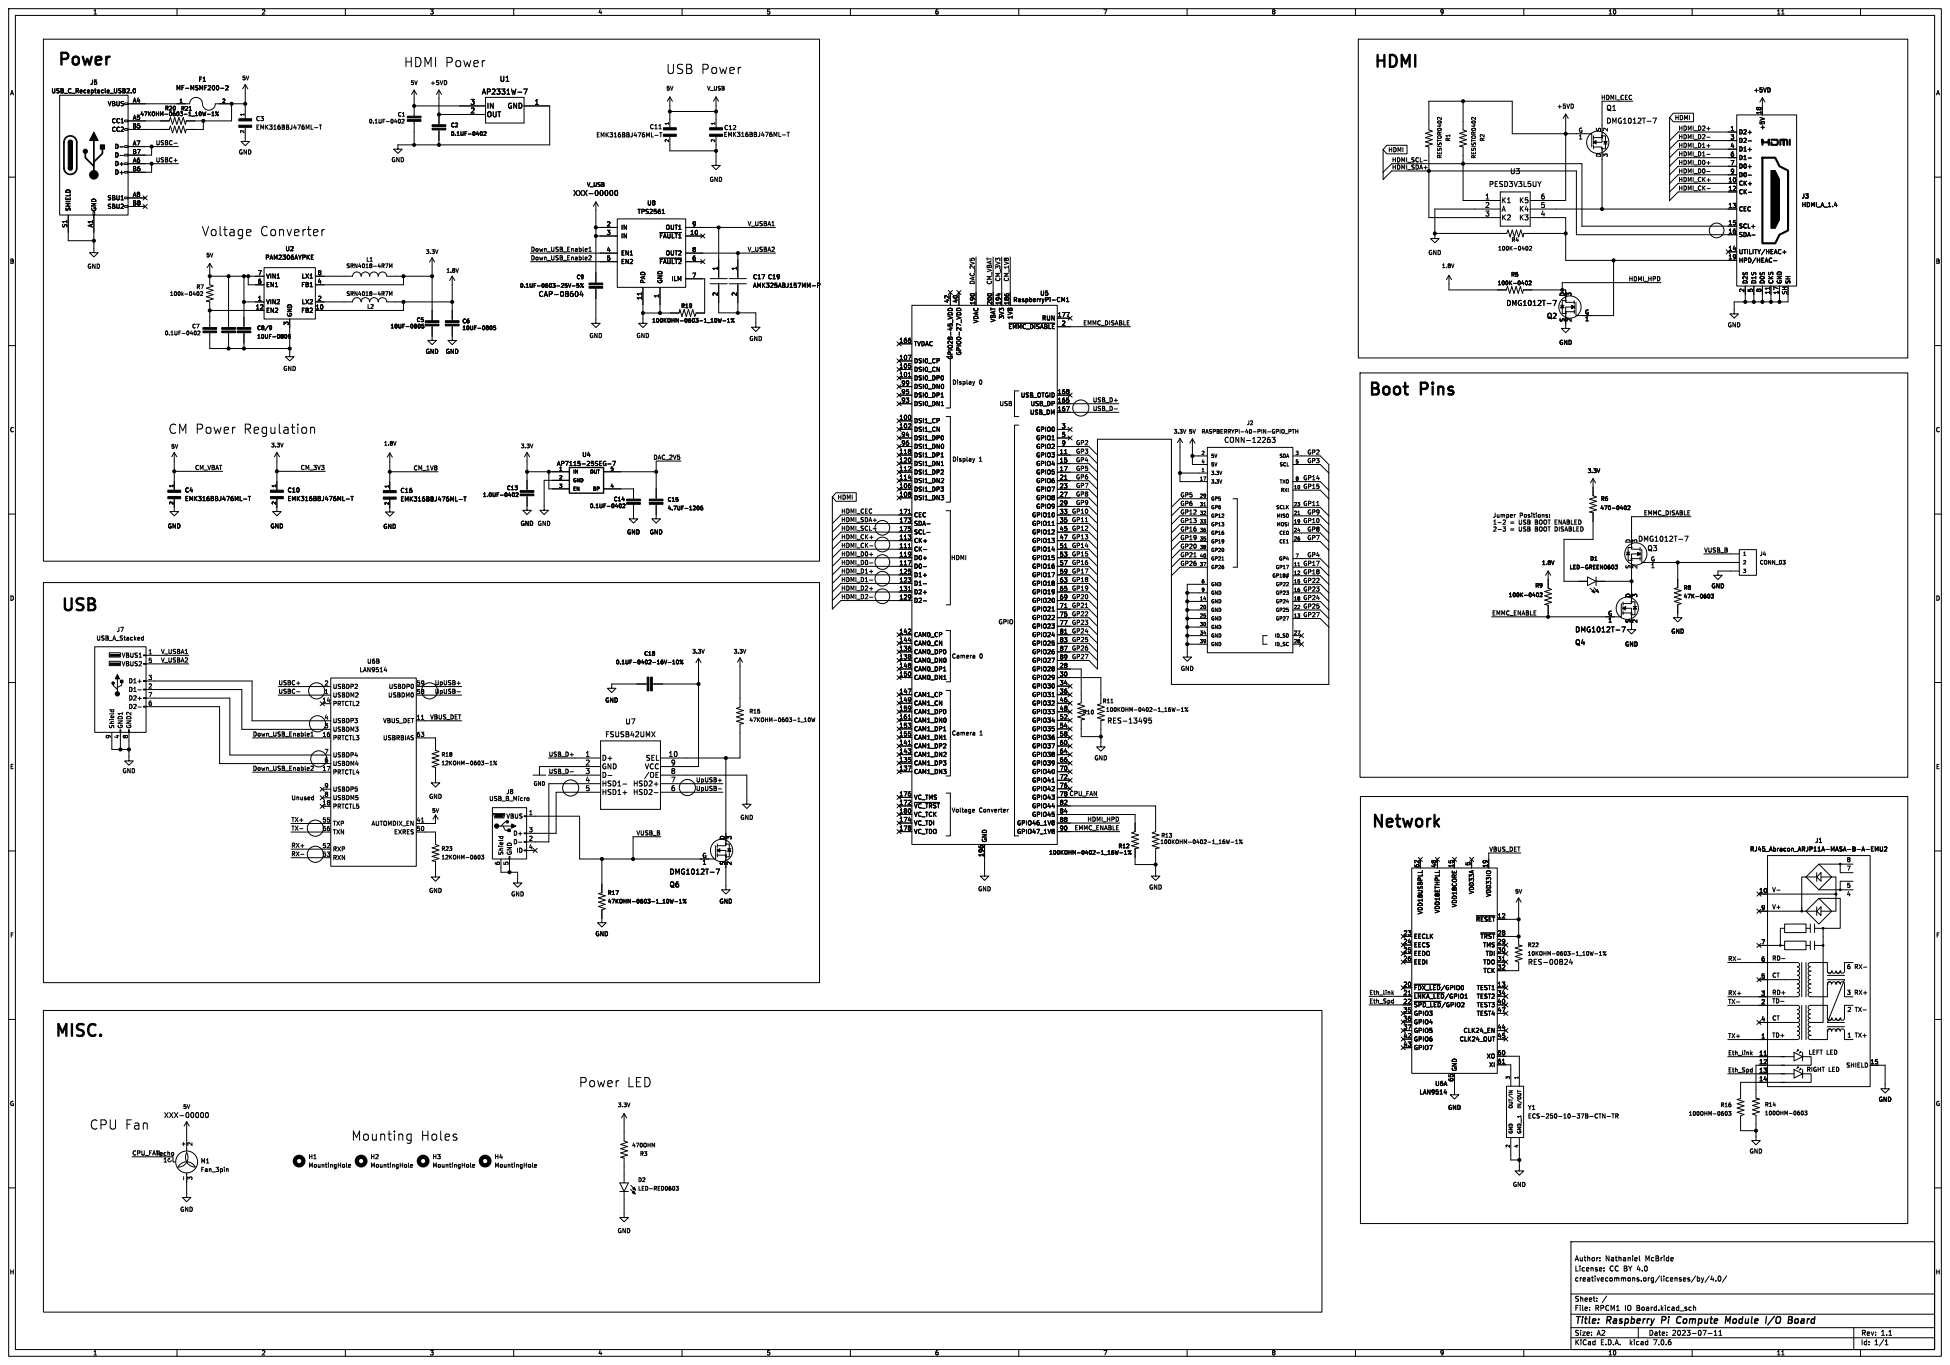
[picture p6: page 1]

TX+ Eth_Spd RX+ TX- RX- Eth_link

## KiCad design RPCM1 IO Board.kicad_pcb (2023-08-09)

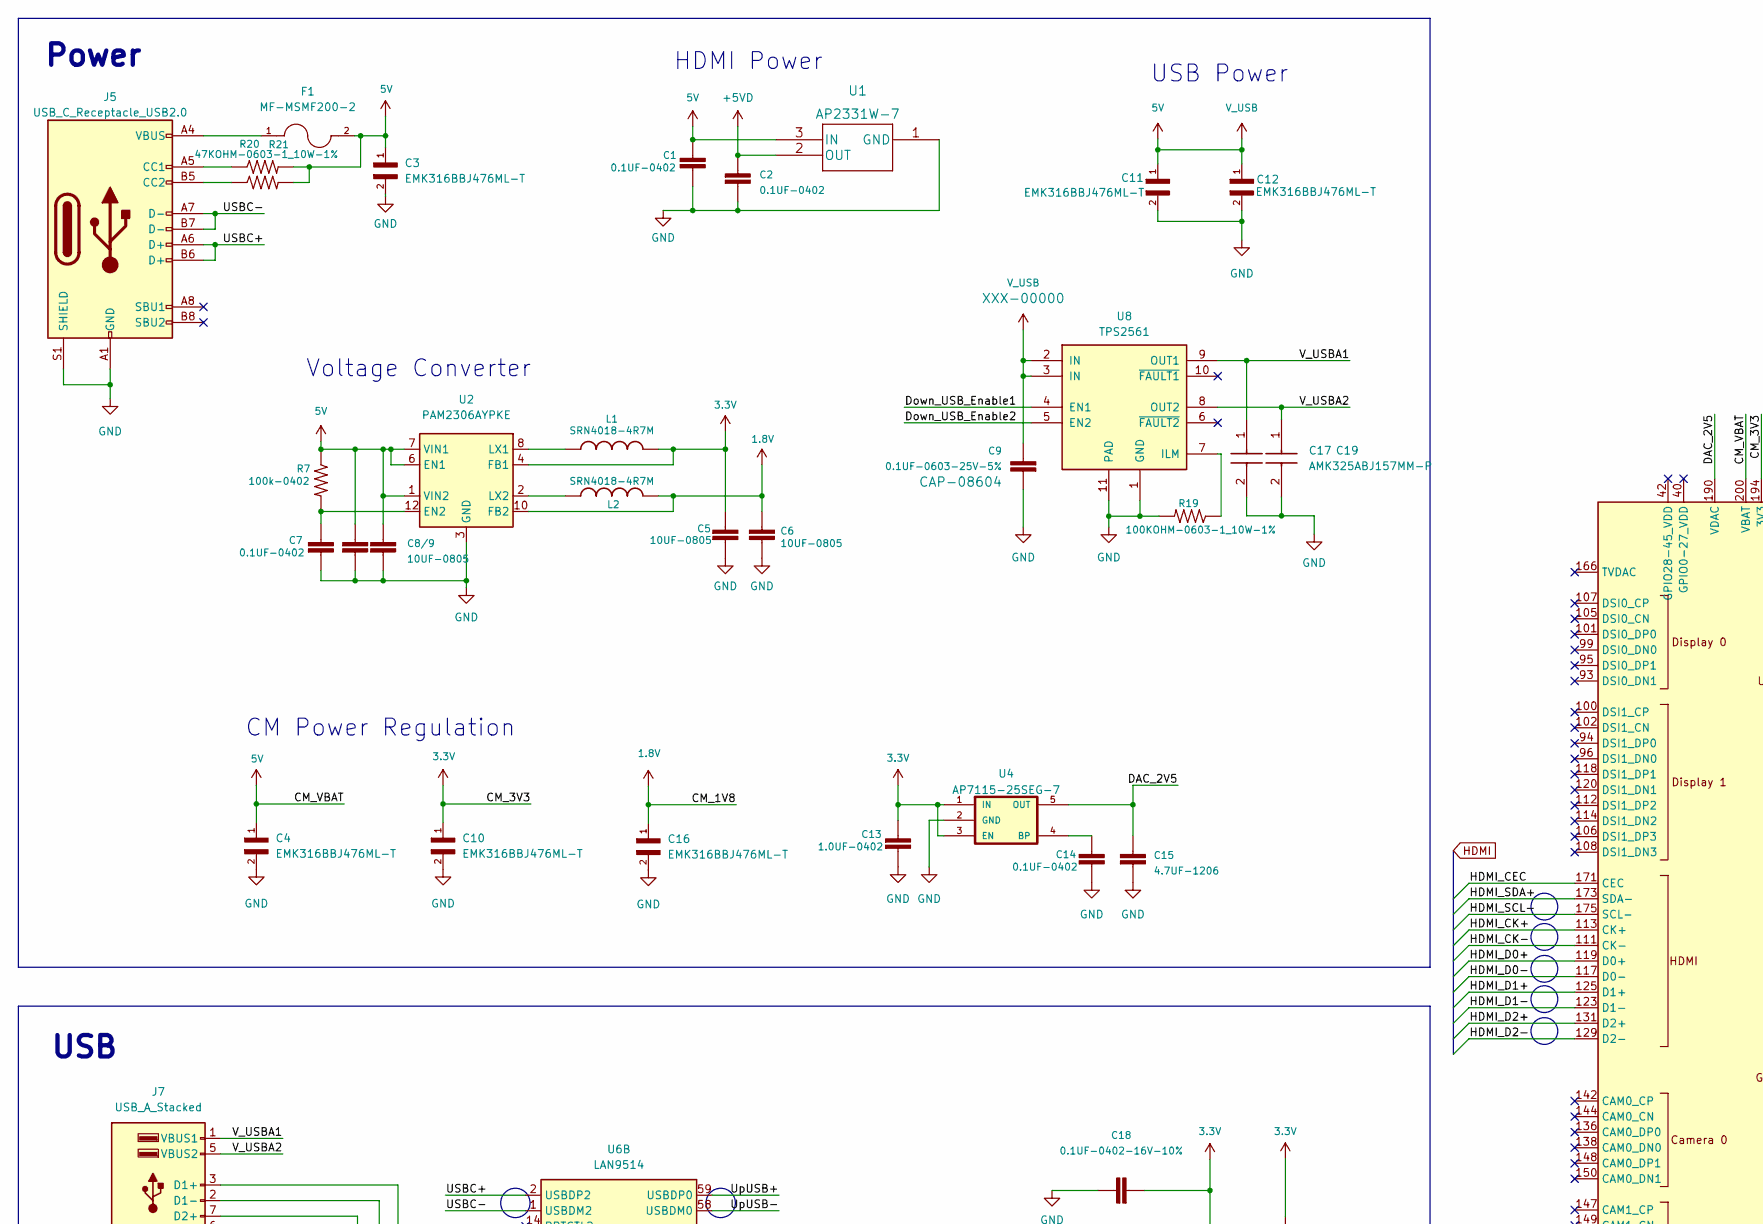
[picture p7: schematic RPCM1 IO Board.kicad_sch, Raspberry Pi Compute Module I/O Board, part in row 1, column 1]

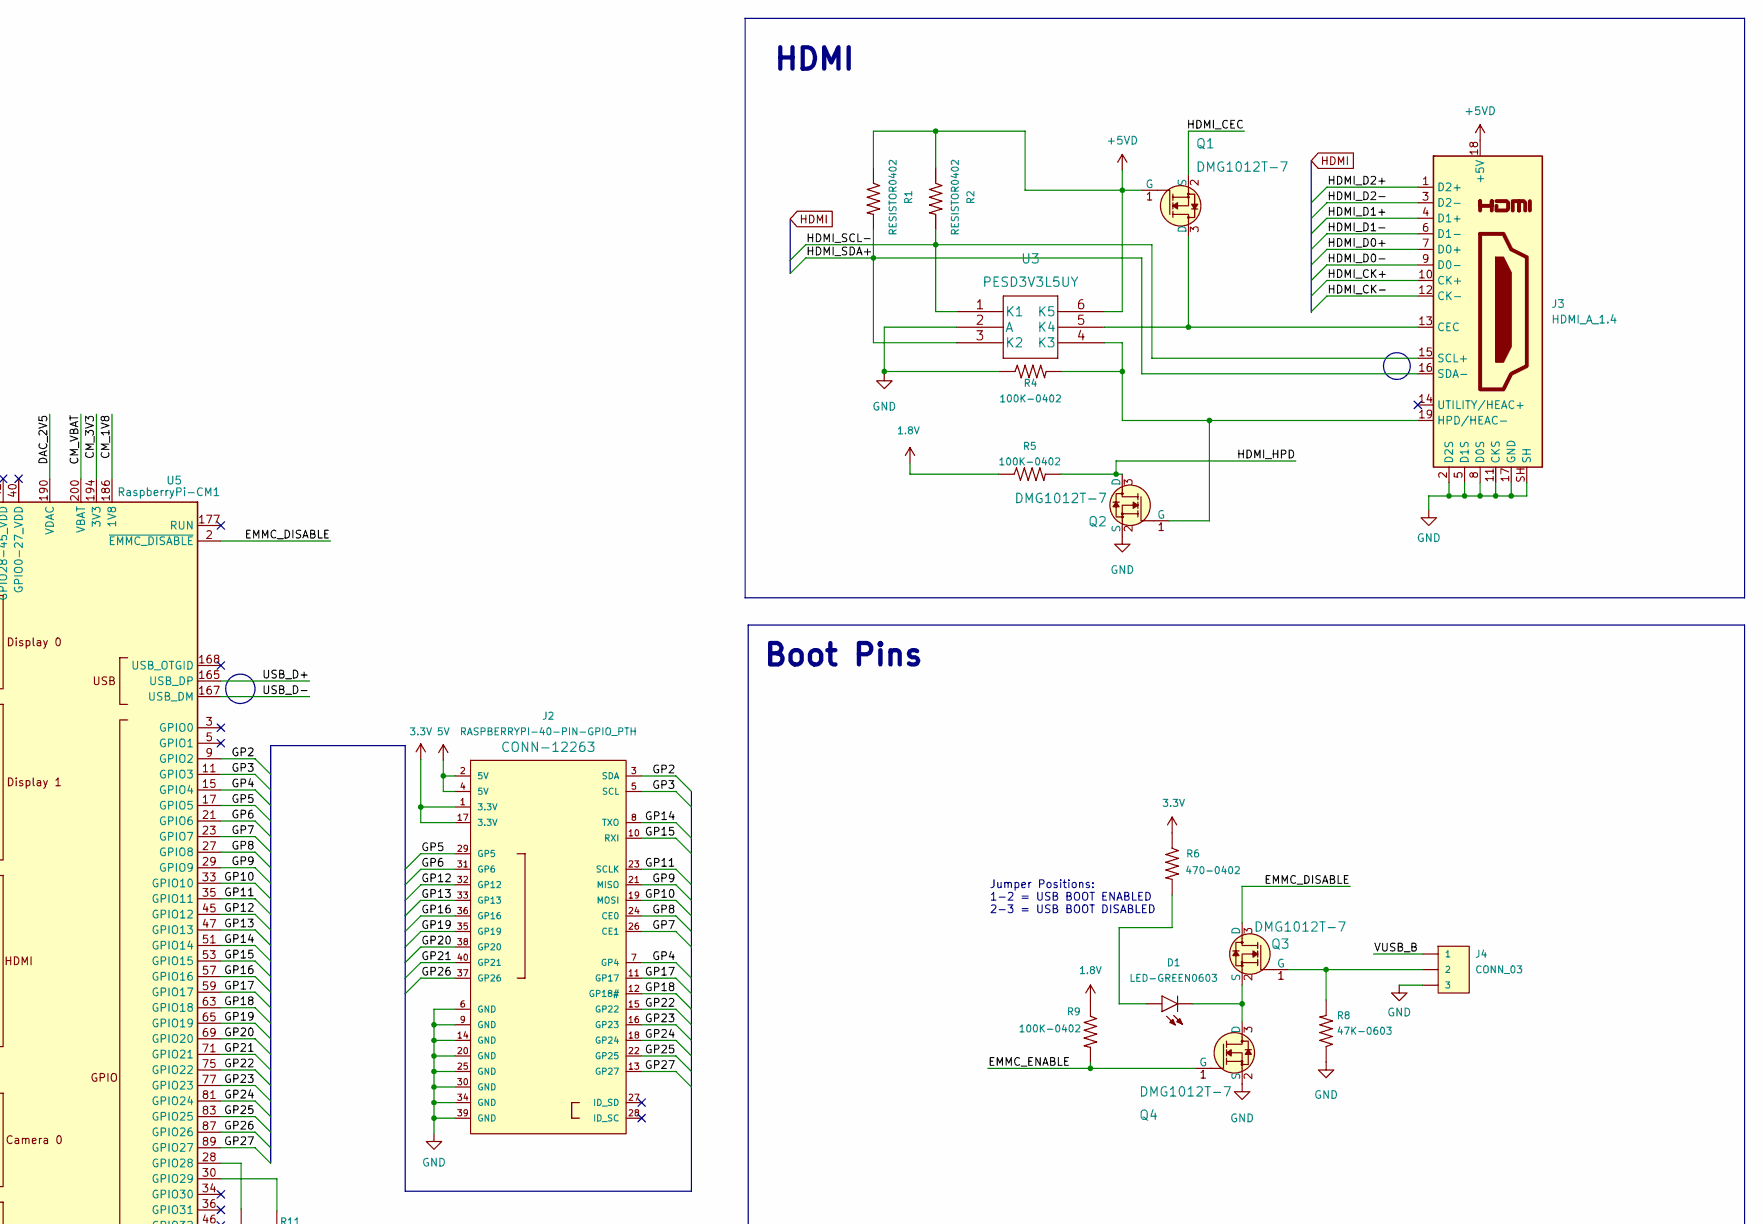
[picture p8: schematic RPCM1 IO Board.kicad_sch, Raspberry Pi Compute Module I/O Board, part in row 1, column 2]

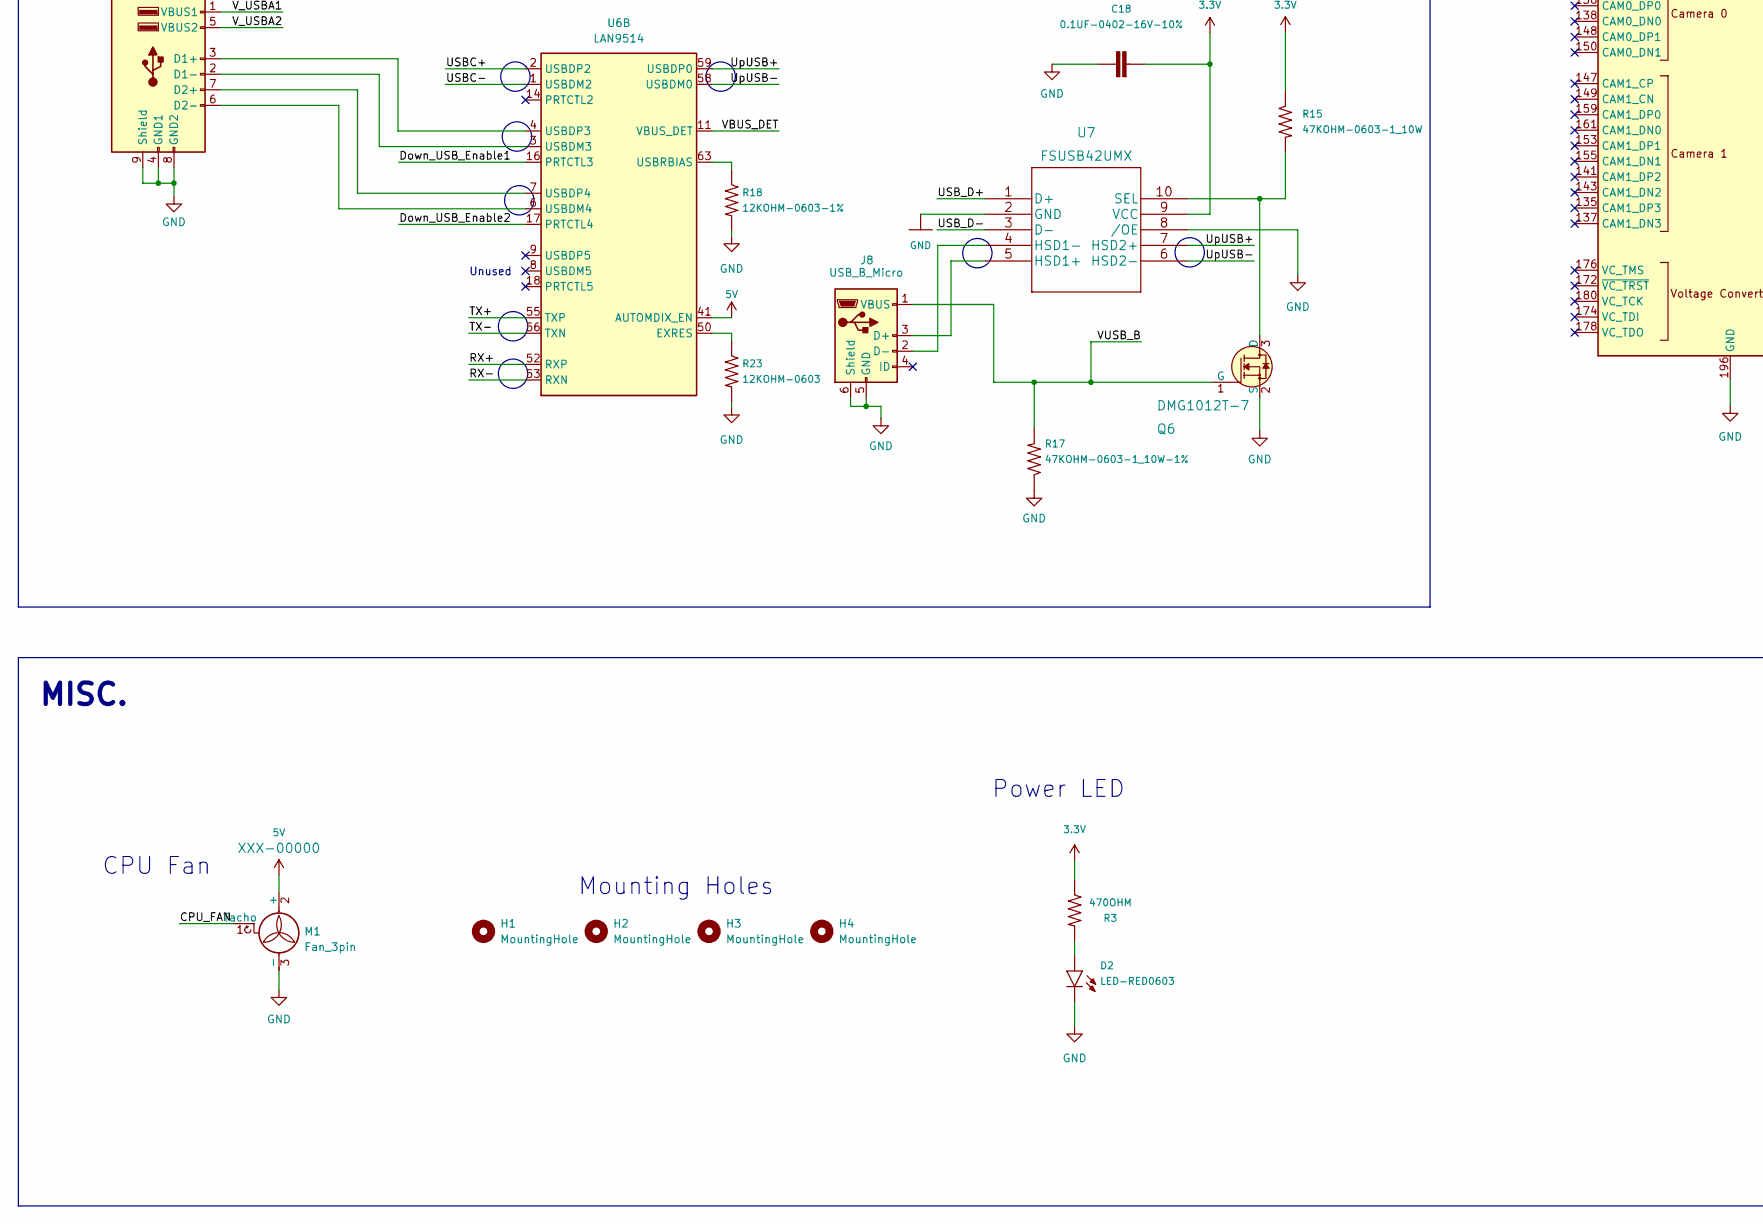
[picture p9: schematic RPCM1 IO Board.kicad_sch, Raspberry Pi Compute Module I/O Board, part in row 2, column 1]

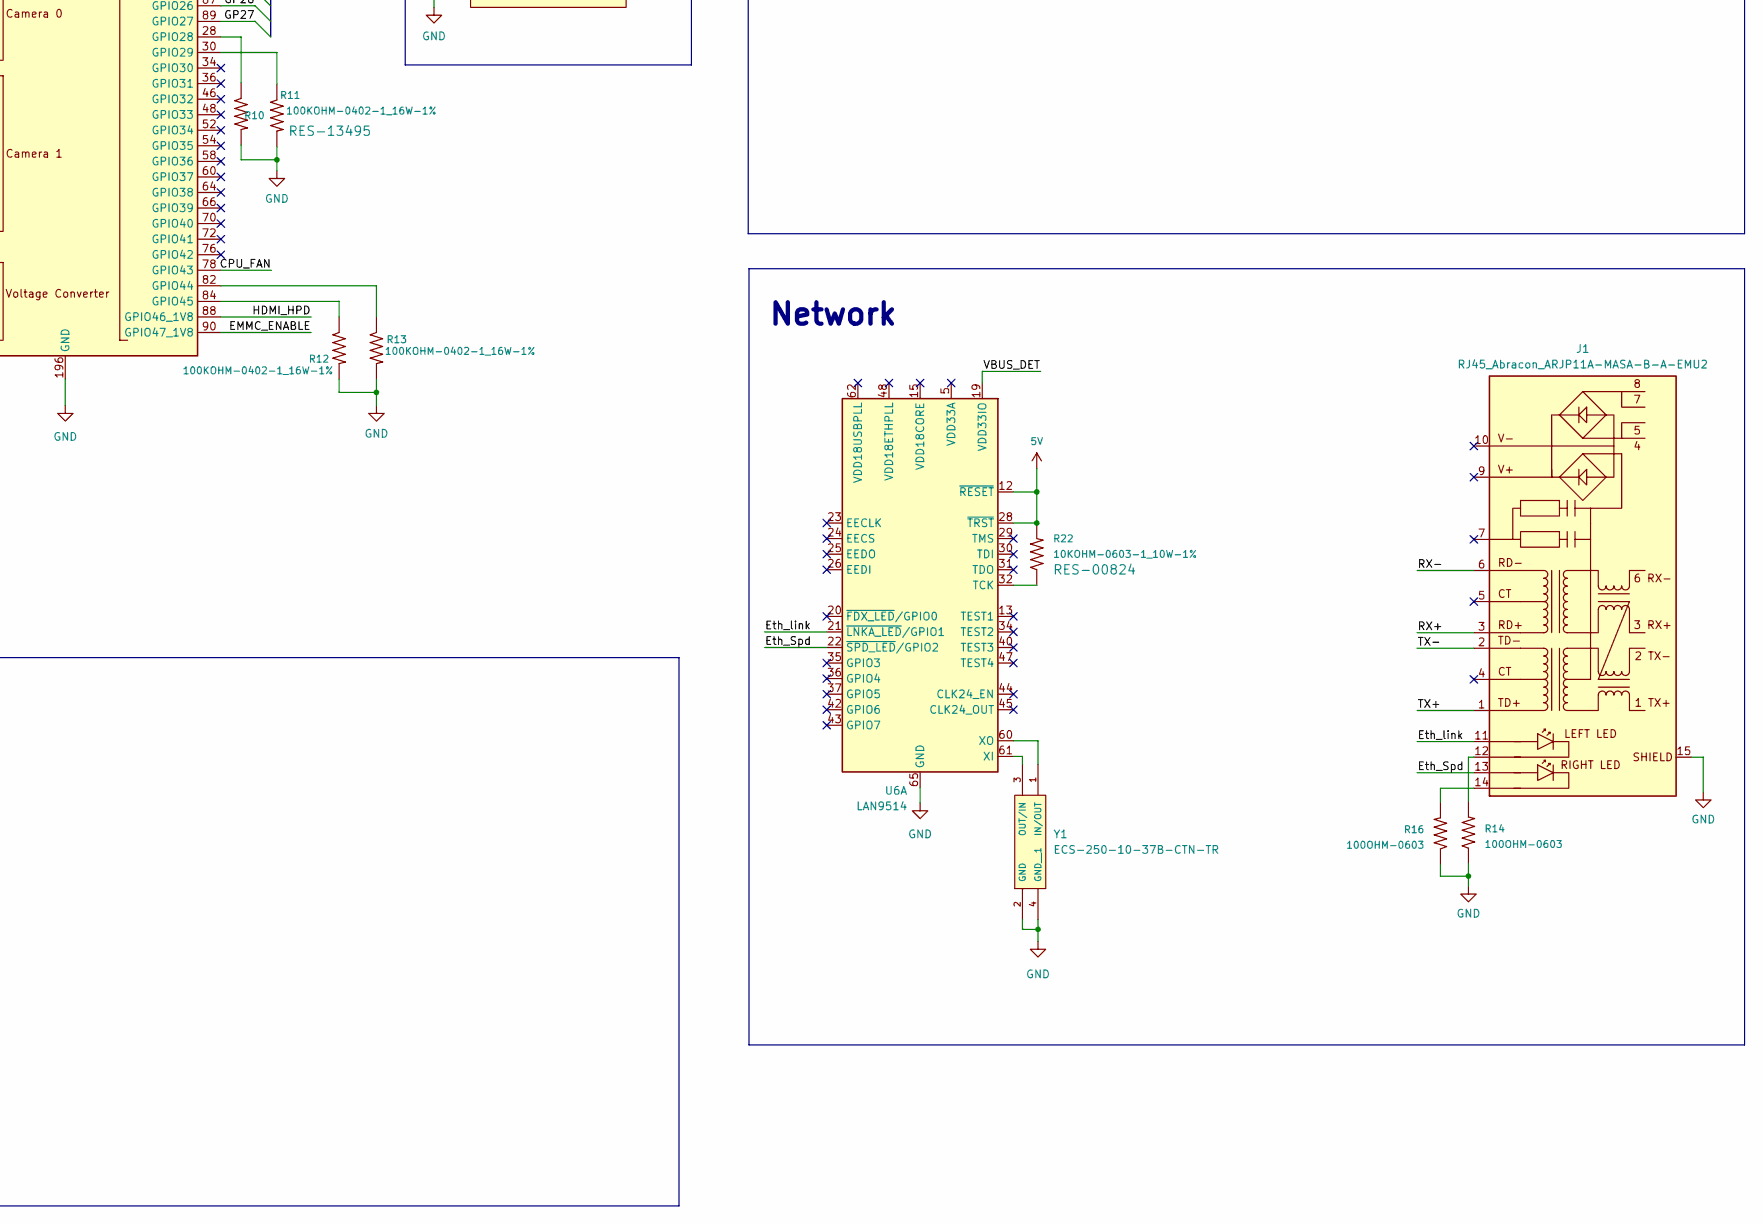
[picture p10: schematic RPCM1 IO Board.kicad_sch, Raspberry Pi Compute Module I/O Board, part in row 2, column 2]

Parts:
C1, C2, C7, C14: 0.1UF-0402; 0402
C3, C4, C10, C11, C12, C16: EMK316BBJ476ML-T; CAPC3216X190N
C5, C6, C8/9: 10UF-0805; 0805
C8: 10UF-0805-10V-10%; 0805
C9: 0.1UF-0603-25V-5%; C_0603_1608Metric
C13: 1.0UF-0402; 0402
C15: 4.7UF-1206; 0603
C17, C19: AMK325ABJ157MM-P; 1210; Mouser Part Number 963-AMK325ABJ157MM-P
C18: 0.1UF-0402-16V-10%; 0402
D1: LED-GREEN0603; LED-0603
D2: LED-RED0603; LED-0603
F1: MF-MSMF200-2
H1, H2, H3, H4: MountingHole; MountingHole_2.2mm_M2_DIN965_Pad_TopBottom
J1: RJ45_Abracon_ARJP11A-MASA-B-A-EMU2; RJ45_Abracon_ARJP11A-MA_Horizontal
J2: RASPBERRYPI-40-PIN-GPIO_PTH; 2X20_NOSILK
J3: HDMI_A_1.4; HDMI_Mini_Female_2001-1-2-21-00-BK
J4: CONN_03; 1X03_NO_SILK
J5: USB_C_Receptacle_USB2.0; USB_C_Receptacle_GCT_USB4085
J7: USB_A_Stacked; USB_A_CUI_UJ2-ADH-TH_Horizontal_Stacked
J8: USB_B_Micro; USB_Micro_B_Female_10118193-0001LF
L1, L2: SRN4018-4R7M
M1: Fan_3pin; 1X03_NO_SILK
Q1, Q2, Q3, Q4, Q6: DMG1012T-7; SOT-523; MPN DMG1012T-7; Digi-Key_PN DMG1012T-7DICT-ND
R1, R2: RESISTOR0402; 0402
R3: 470OHM; 0402
R4, R5: 100K-0402; R_01005_0402Metric
R6: 470-0402; 0402
R7: 100k-0402; 0402
R8: 47K-0603; 0603
R9: 100K-0402; 0402
R10, R11, R12, R13: 100KOHM-0402-1_16W-1%; 0402
R14, R16: 100OHM-0603; R_0603_1608Metric
R15: 47KOHM-0603-1_10W; 0603
R17: 47KOHM-0603-1_10W-1%; 0603
R18: 12KOHM-0603-1%; R_0603_1608Metric
R19: 100KOHM-0603-1_10W-1%; R_0603_1608Metric
R20, R21: 47KOHM-0603-1_10W-1%; R_0603_1608Metric
R22: 10KOHM-0603-1_10W-1%; R_0603_1608Metric
R23: 12KOHM-0603; R_0603_1608Metric
U1: AP2331W-7
U2: PAM2306AYPKE; WDFN-12-1EP_3x3mm_P0.45mm_EP1.7x2.5mm
U3: PESD3V3L5UY
U4: AP7115-25SEG-7; AP7115-25SEG; PARTREV 12
U5: RaspberryPi-CM1; TE_1717254-4
U6: LAN9514; QFN-64-1EP_9x9mm_P0.5mm_EP7.3x7.3mm
U7: FSUSB42UMX
U8: TPS2561; VSON-10-1EP_3x3mm_P0.5mm_EP1.65x2.4mm_ThermalVias
Y1: ECS-250-10-37B-CTN-TR; CRYSTAL-SMD-3.2X2.5MM; PARTREV 2017

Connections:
1.8V: C6.1, C16.1, L2.1, R5.1, R9.1, U2.10 (FB2), U5.183 (1V8), U5.184 (1V8), U5.185 (1V8), U5.186 (1V8)
3.3V: C5.1, C10.1, C13.1, C18.2, J2.1 (3.3V), J2.17 (3.3V), L1.1, R3.1, R6.1, R15.1, U2.4 (FB1), U4.1 (IN), U4.3 (EN), U5.191 (3V3), U5.192 (3V3), U5.193 (3V3), U5.194 (3V3), U7.9 (VCC)
5V: C1.1, C3.1, C4.1, C8.1, C8/9.1, C9.1, C11.1, C12.1, F1.2, J2.2 (5V), J2.4 (5V), M1.2 (+), R7.1, R20.2, R21.2, R22.2, U1.3 (IN), U2.1 (VIN2), U2.6 (EN1), U2.7 (VIN1), U5.197 (VBAT), U5.198 (VBAT), U5.199 (VBAT), U5.200 (VBAT), U6.12 (~RESET), U6.28 (~TRST), U6.41 (AUTOMDIX_EN), U8.2 (IN), U8.3 (IN); also elsewhere on the board
+5VD: C2.1, J3.18 (+5V), Q1.1 (G), R1.1, R2.1, U1.2 (OUT), U3.6 (K5)
/CPU_FAN: M1.1 (Tacho), U5.78 (GPIO43)
/DAC_2V5: C15.1, U4.5 (OUT), U5.189 (VDAC), U5.190 (VDAC)
/Down_USB_Enable1: U6.16 (PRTCTL3), U8.4 (EN1)
/Down_USB_Enable2: U6.17 (PRTCTL4), U8.5 (EN2)
/EMMC_DISABLE: Q3.3 (D), U5.2 (~EMMC_DISABLE)
/EMMC_ENABLE: Q4.1 (G), R9.2, U5.90 (GPIO47_1V8)
/Eth_Spd: J1.13 (RLED+), U6.22 (~SPD_LED/GPIO2)
/Eth_link: J1.11 (LLED+), U6.21 (~LNKA_LED/GPIO1)
/GP2: J2.3 (SDA), U5.9 (GPIO2)
/GP3: J2.5 (SCL), U5.11 (GPIO3)
/GP4: J2.7 (GP4), U5.15 (GPIO4)
/GP5: J2.29 (GP5), U5.17 (GPIO5)
/GP6: J2.31 (GP6), U5.21 (GPIO6)
/GP7: J2.26 (CE1), U5.23 (GPIO7)
/GP8: J2.24 (CE0), U5.27 (GPIO8)
/GP9: J2.21 (MISO), U5.29 (GPIO9)
/GP10: J2.19 (MOSI), U5.33 (GPIO10)
/GP11: J2.23 (SCLK), U5.35 (GPIO11)
/GP12: J2.32 (GP12), U5.45 (GPIO12)
/GP13: J2.33 (GP13), U5.47 (GPIO13)
/GP14: J2.8 (TXO), U5.51 (GPIO14)
/GP15: J2.10 (RXI), U5.53 (GPIO15)
/GP16: J2.36 (GP16), U5.57 (GPIO16)
/GP17: J2.11 (GP17), U5.59 (GPIO17)
/GP18: J2.12 (GP18#), U5.63 (GPIO18)
/GP19: J2.35 (GP19), U5.65 (GPIO19)
/GP20: J2.38 (GP20), U5.69 (GPIO20)
/GP21: J2.40 (GP21), U5.71 (GPIO21)
/GP22: J2.15 (GP22), U5.75 (GPIO22)
/GP23: J2.16 (GP23), U5.77 (GPIO23)
/GP24: J2.18 (GP24), U5.81 (GPIO24)
/GP25: J2.22 (GP25), U5.83 (GPIO25)
/GP26: J2.37 (GP26), U5.87 (GPIO26)
/GP27: J2.13 (GP27), U5.89 (GPIO27)
/HDMI_CEC: Q1.2 (S), U5.171 (CEC)
/HDMI_CK+: J3.10 (CK+), U5.113 (CK+)
/HDMI_CK-: J3.12 (CK-), U5.111 (CK-)
/HDMI_D0+: J3.7 (D0+), U5.119 (D0+)
/HDMI_D0-: J3.9 (D0-), U5.117 (D0-)
/HDMI_D1+: J3.4 (D1+), U5.125 (D1+)
/HDMI_D1-: J3.6 (D1-), U5.123 (D1-)
/HDMI_D2+: J3.1 (D2+), U5.131 (D2+)
/HDMI_D2-: J3.3 (D2-), U5.129 (D2-)
/HDMI_HPD: Q2.3 (D), R5.2, U5.88 (GPIO46_1V8)
/HDMI_SCL: J3.15 (SCL+), R2.2, U3.1 (K1), U5.175 (SCL-)
/HDMI_SDA: J3.16 (SDA-), R1.2, U3.3 (K2), U5.173 (SDA-)
/RX+: J1.3 (RD+), U6.52 (RXP)
/RX-: J1.6 (RD-), U6.53 (RXN)
/TX+: J1.1 (TD+), U6.55 (TXP)
/TX-: J1.2 (TD-), U6.56 (TXN)
/USBC+: J5.A6 (D+), J5.B6 (D+), U6.2 (USBDP2)
/USBC-: J5.A7 (D-), J5.B7 (D-), U6.1 (USBDM2)
/USB_D+: U5.165 (USB_DP), U7.1 (D+)
/USB_D-: U5.167 (USB_DM), U7.3 (D-)
/UpUSB+: U6.59 (USBDP0), U7.7 (HSD2+)
/UpUSB-: U6.58 (USBDM0), U7.6 (HSD2-)
/VBUS_DET: U6.11 (VBUS_DET), U6.19 (VDD33IO), U6.27 (VDD33IO), U6.33 (VDD33IO), U6.39 (VDD33IO), U6.46 (VDD33IO)
/VUSB_B: J4.1, J8.1 (VBUS), Q6.1 (G), R17.2
/V_USBA1: C19.1, J7.1 (VBUS1), U8.9 (OUT1)
/V_USBA2: C17.1, J7.5 (VBUS2), U8.8 (OUT2)
GND: C1.2, C2.2, C3.2, C4.2, C5.2, C6.2, C7.2, C8.2, C8/9.2, C9.2, C10.2, C11.2, C12.2, C13.2, C14.2, C15.2, C16.2, C17.2, C18.1, C19.2, D2.C, J1.15 (SHIELD), J2.6 (GND), J2.9 (GND), J2.14 (GND), J2.20 (GND), J2.25 (GND), J2.30 (GND), J2.34 (GND), J2.39 (GND), J3.2 (D2S), J3.5 (D1S), J3.8 (D0S), J3.11 (CKS), J3.17 (GND), J3.SH, J4.3, J5.A1 (GND), J5.A12 (GND), J5.B1 (GND), J5.B12 (GND), J5.S1 (SHIELD), J7.4 (GND1), J7.8 (GND2), J7.9 (Shield), J8.5 (GND), J8.6 (Shield), M1.3 (-), Q2.2 (S), Q4.2 (S), Q6.2 (S), R4.1, R8.1, R10.2, R11.2, R12.2, R13.2, R14.1, R16.1, R17.1, R18.2, R19.2, R23.2, U1.1 (GND), U2.3 (GND), U2.9 (GND), U2.13 (GND), U3.2 (A), U4.2 (GND), U5.1 (GND), U5.7 (GND), U5.13 (GND), U5.19 (GND), U5.25 (GND), U5.26 (GND), U5.31 (GND), U5.32 (GND), U5.37 (GND), U5.38 (GND), U5.43 (GND), U5.44 (GND), U5.49 (GND), U5.50 (GND), U5.55 (GND), U5.56 (GND), U5.61 (GND), U5.62 (GND), U5.67 (GND), U5.68 (GND), U5.73 (GND), U5.74 (GND), U5.79 (GND), U5.80 (GND), U5.85 (GND), U5.86 (GND), U5.91 (GND), U5.92 (GND), U5.97 (GND), U5.98 (GND), U5.103 (GND), U5.104 (GND), U5.109 (GND), U5.110 (GND), U5.115 (GND), U5.116 (GND), U5.121 (GND), U5.122 (GND), U5.127 (GND), U5.133 (GND), U5.134 (GND), U5.139 (GND), U5.140 (GND), U5.145 (GND), U5.146 (GND), U5.151 (GND), U5.152 (GND), U5.157 (GND), U5.163 (GND), U5.164 (GND), U5.169 (GND), U5.170 (GND), U5.181 (GND), U5.182 (GND), U5.187 (GND), U5.188 (GND), U5.195 (GND), U5.196 (GND), U6.65 (GND), U7.2 (GND), U7.8 (/OE), U8.1 (GND), U8.11 (PAD), Y1.2 (GND), Y1.4 (GND__1); also elsewhere on the board
J7-D1+: J7.3 (D1+), U6.4 (USBDP3)
J7-D1-: J7.2 (D1-), U6.3 (USBDM3)
J7-D2+: J7.7 (D2+), U6.7 (USBDP4)
J7-D2-: J7.6 (D2-), U6.6 (USBDM4)
J8-D+: J8.3 (D+), U7.5 (HSD1+)
J8-D-: J8.2 (D-), U7.4 (HSD1-)
unnamed: D1.A, R6.2
unnamed: D2.A, R3.2
unnamed: F1.1, J5.A4 (VBUS), J5.A9 (VBUS), J5.B4 (VBUS), J5.B9 (VBUS)
unnamed: J1.12 (LLED-), R14.2
unnamed: J1.14 (RLED-), R16.2
unnamed: J3.13 (CEC), Q1.3 (D), U3.5 (K4)
unnamed: J3.19 (HPD/HEAC-), Q2.1 (G), R4.2, U3.4 (K3)
unnamed: J5.A5 (CC1), R20.1
unnamed: J5.B5 (CC2), R21.1
unnamed: J4.2, Q3.1 (G), R8.2
unnamed: D1.C, Q3.2 (S), Q4.3 (D)
unnamed: Q6.3 (D), R15.2, U7.10 (SEL)
unnamed: C7.1, R7.2, U2.12 (EN2)
unnamed: L1.2, U2.8 (LX1)
unnamed: L2.2, U2.2 (LX2)
unnamed: C14.1, U4.4 (BP)
unnamed: R10.1, U5.28 (GPIO28)
unnamed: R11.1, U5.30 (GPIO29)
unnamed: R13.1, U5.82 (GPIO44)
unnamed: R12.1, U5.84 (GPIO45)
unnamed: R22.1, U6.32 (TCK)
unnamed: R23.1, U6.50 (EXRES)
unnamed: R18.1, U6.63 (USBRBIAS)
unnamed: R19.1, U8.7 (ILM)
U6A-XI: U6.61 (XI), Y1.3 (OUT/IN)
\U6A-XO: U6.60 (XO), Y1.1 (IN/OUT)

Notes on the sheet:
Boot Pins
HDMI
USB
CPU Fan
USB Power
MISC.
Jumper Positions: 1-2 = USB BOOT ENABLED 2-3 = USB BOOT DISABLED
Network
Power
Mounting Holes
HDMI Power
Power LED
Voltage Converter
CM Power Regulation
Unused

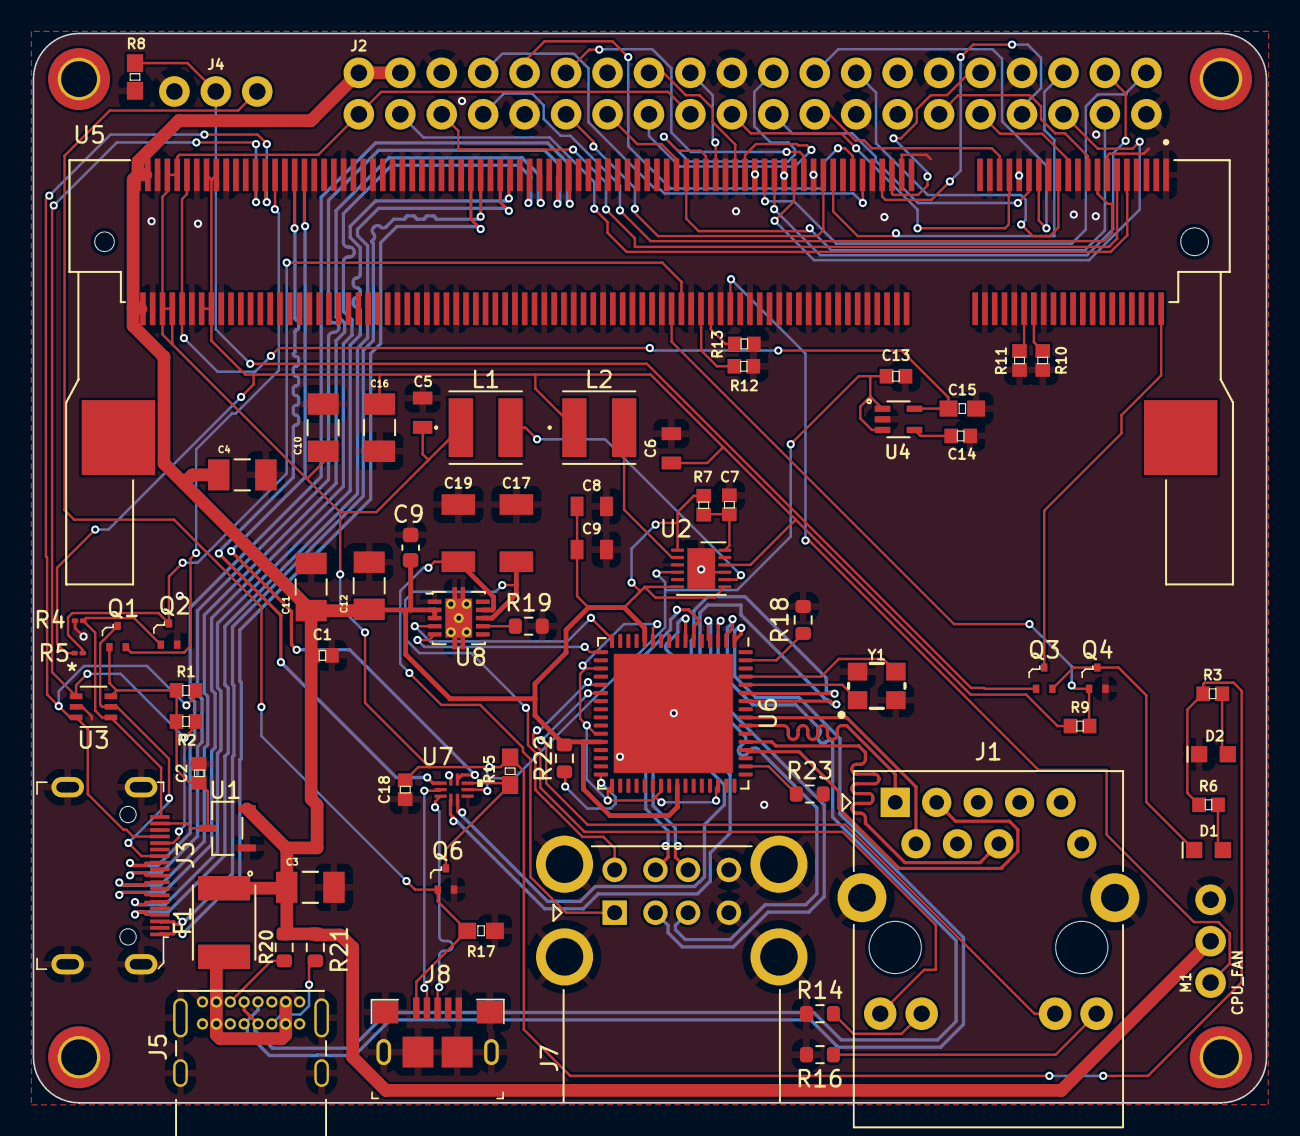
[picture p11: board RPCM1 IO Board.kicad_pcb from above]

Board: 2 copper layers, 75.6 x 65.5 mm, 74 parts (0 on the bottom side), 97 nets.

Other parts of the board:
C9#2: 0.1UF-0603-25V-5%; C_0603_1608Metric

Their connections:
5V: C9#2.1; also elsewhere on the board
GND: C9#2.2; also elsewhere on the board

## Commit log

2023-01-11 Added Schematic/Gerber Files
    [RPCM1 IO Board.kicad_pcb, RPCM1 IO Board.kicad_sch]
2023-01-11 Added PCB images
2023-01-11 Uploaded BOM
    [RPCM1 IO Board.csv]
2023-01-11 Rename RPCM1 IO Board.csv to RPCMIOBoard_BOM.csv
    [RPCMIOBoard_BOM.csv]
2023-01-11 Added PDFs and Gerbers
    [RPCM1 IO Board-B_Cu.gbr, RPCM1 IO Board-B_Mask.gbr, RPCM1 IO Board-B_Silkscreen.gbr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]
2023-01-11 Created Gerber folder
    [RPCM1 IO Board-B_Cu.gbr, RPCM1 IO Board-B_Mask.gbr, RPCM1 IO Board-B_Silkscreen.gbr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]
2023-01-11 Deleted redundant Gerber files
    [RPCM1 IO Board-B_Cu.gbr]
2023-01-11 Added PCB rendered images
2023-06-23 Added images of raw and assembled board
2023-08-09 Added new files
    [RPCM1 IO Board.kicad_pcb, RPCM1 IO Board.kicad_sch]
2023-08-22 Update and rename Footprints.pretty to Footprints/a
2023-08-22 Added Footprints
2023-08-22 Update README.md with instructions
    Added steps for instillation that instruct the user to rename the footprints folder and add the symbols/footprints to their project specific libraries.

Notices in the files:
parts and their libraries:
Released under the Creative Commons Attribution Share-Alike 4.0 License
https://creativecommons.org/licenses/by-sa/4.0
